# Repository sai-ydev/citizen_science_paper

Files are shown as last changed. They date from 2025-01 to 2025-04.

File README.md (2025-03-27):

# Purple Daisy RP2350A STEAM Platform #

This is the repository for the Purple Daisy Platform based on the [Raspberry Pi RP2350A Microcontroller](https://www.raspberrypi.com/products/rp2350/). This is an open-source platform to conduct citizen science experiments using the Raspberry Pi RP2350A microcontroller. 

The board looks something like shown in the image below:

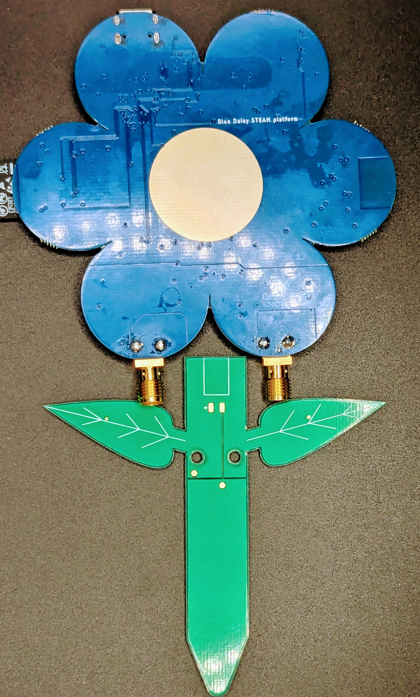
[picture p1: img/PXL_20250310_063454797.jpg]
Purple Daisy Front

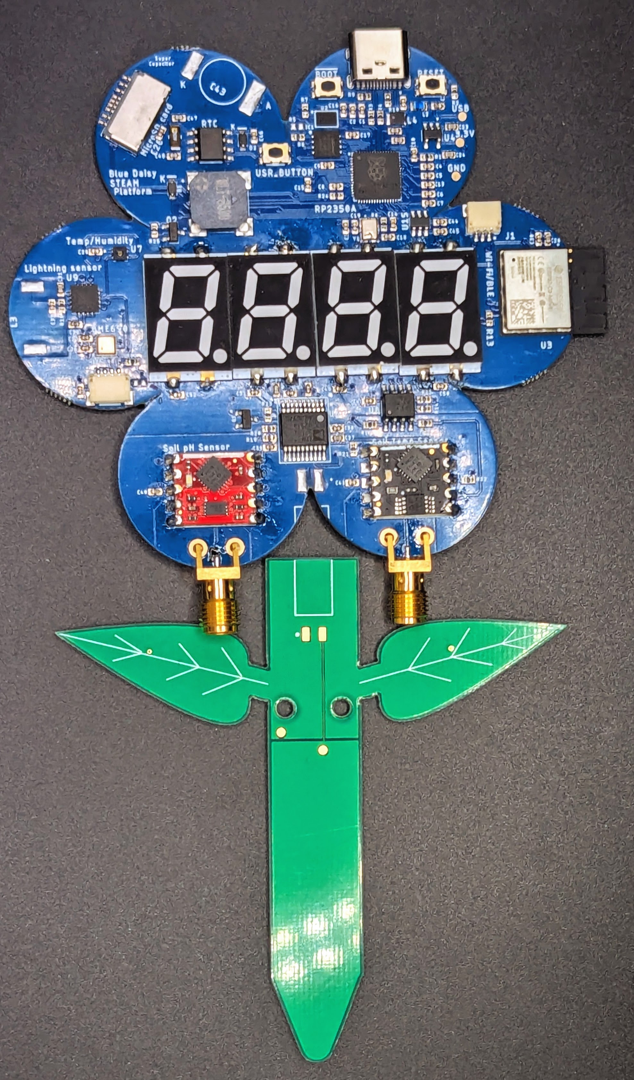
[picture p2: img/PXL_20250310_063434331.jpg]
Purple Daisy


The components of the board are highlighted in the image below. They are as follows:

1. Raspberry PI RP2350A microcontroller
2. RGB seven segment display - 4 characters
3. MicroSD card slot
4. Buzzer
5. WiFi Module
6. USB-C port
7. Soil Moisture sensor
8. AS3935 Lightning Sensor
9. pH Sensor + Conditioning Circuit
10. Liquid Temperature sensor
11. QwiiC I2C Sensor port to connect additional sensors
12. Real Time Clock for Calendar Keeping
13. Debug Port for debugging
14. BME690 Air Quality Sensor
15. ENS210 Temperature Humidity Sensor

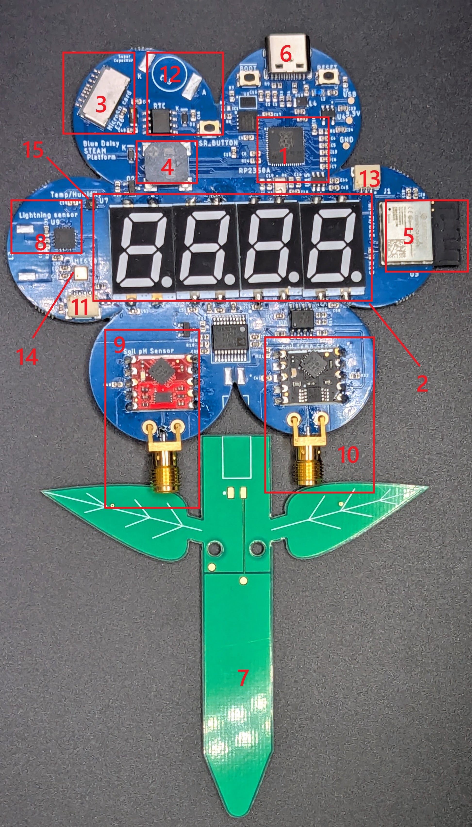
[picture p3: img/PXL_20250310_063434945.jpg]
Highlights


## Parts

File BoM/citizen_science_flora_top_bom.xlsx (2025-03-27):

Comment | Designator | Footprint | LCSC Part #
 | J3 | JST-4-1.25 | C160404
0.1uF | C1 C2 C3 C4 C5 C6 C7 C8 C9 C13 C15 C16 C17 C21 C22 C25 C26 C27 C28 C29 C30 C34 C36 C38 C39 C40 C41 C42 C44 C45 C46 C49 C50 C51 C52 | 0402-TIGHT | C1525
1.0uF | C32 | 0402 | C14445
1K | R2 R6 R8 R14 R15 | 0402 | C11702
1M | R23 R24 | 0402 | C26083
1N5819 | D1 D2 | SOD-323 | C2100
1nF | C33 | 0402 | C1523
2.2K | R12 R21 R22 | 0402 | C25879
3.3µH | L4 | 0805 | C42411119
4.7uF | C10 C11 C12 C14 | 0402-TIGHT | C23733
5.1k | R9 R10 | 0402 | C25905
10K | R18 R20 R7 R13 | 0402-TIGHT | C25531
10uF | C20 C23 C24 C31 C35 C37 | 0402-TIGHT | C15525
12MHz | Y1 | CRYSTAL-SMD-3.2X2.5MM | C20625731
12pF | C47 C48 | 0402 | C1547
15pF | C18 C19 | 0402 | C1548
16.9K | R19 | 0402 | C25858
DNP | R5 | 0402 | DNF
27 | R3 R4 | 0402-TIGHT | C3017771
33 | R1 | 0402 | C25105
100 | R16 R17 | 0402-TIGHT | C25076
BSS138 | Q1 Q2 | SOT23-3 | C12298
470 | R25 | 0402 | C208892
60312202114511 | J4 J5 | 60312202114511 | DNF
ADM3260ARSZ | U6 | SSOP20 | C658204
APS6404L-3SQR-ZR | U2 | APS6404L-3SQR-ZR | C3040877
AS3935-BQFT | U9 | QFN65P400X400X80-17N | C3178344
BME690 | U5 | IC_BME688 | BME690
DNF | R11 | 0402 | DNF
ENS210-LQFM | U7 | XDCR_ENS210-LQFM | C2991202
ESP32-C3-MINI-1-N4 | U3 | XCVR_ESP32-C3-MINI-1-N4 | C2934569
LQW18AN2N2D10D | L2 | INDC1608X100N | C71648
MA5532-AE | L3 | MA5532-AE | DNF
MIC5504-3.3YM5-T5 | U4 | SOT95P280X145-5N | C3021093
MLT-8530 | LS1 | XDCR_CMT-8504-100-SMT-TR | C94599
MOMENTARY-SWITCH-SPST-SMD-4.6X2.8MM | !BOOT RESET USR_BUTTON | TACTILE_SWITCH_SMD_4.6X2.8MM | C72443
OPS-S56AAF5 | U11 U12 U13 U14 | OPS-S56AAF5 | DNF
PCF8563T/F4 118 | U10 | SOIC127P600X175-8N | C80798
PH-OEM | U$2 U$3 | PH_SENSOR | DNF
Q13FC1350000400 | XTAL1 | XTAL_FC-135_EPS | C48615
RP2350A | U1 | RP2350A | C42411118
RSCSK2043R3D01004T | C43 | RSCSK2043R3D01004T | DNF
SFH6325-X017TEL0631 | U8 | SOIC127P599X175-8N | C465944
SM03B-SRSS-TB(LF)(SN) | J1 | JST_SM03B-SRSS-TB(LF)(SN) | C160403
SN74LVC1T45DBVRG4 | U15 | SOT95P280X145-6N | C7843
TF-123-ARP9HXX | U$1 | MICROSDCARD | C2982548
TPB1 27 | 3.3V | B1 27 | DNF
TPB1 27 | GND | B1 27 | DNF
TSM-102-02-S-SH | J6 | SAMTEC_TSM-102-02-S-SH | DNF
TYPE-C-31-M-12 | J2 | HRO_TYPE-C-31-M-12 | C165948
V_USB | USB | B1 27 | DNF
W25Q64JVXGIQ | IC1 | SON80P400X400X50-9N | C2940195

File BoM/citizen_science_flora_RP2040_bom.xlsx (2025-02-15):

Comment | Designator | Footprint | LCSC Part #
Qwiic | J3 | JST_SM04B-SRSS-TB(LF)(SN) | C160404
12MHz | Q3 | NXP-3225 | C20625731
0.1uF | C1 C2 C5 C6 C7 C8 C9 C10 C11 C14 C17 C21 C22 C25 C26 C27 C28 C29 C30 C34 C36 C38 C39 C40 C41 C42 C44 C45 C46 C49 C50 C51 C52 | 0402 | C1525
1.0uF | C3 C4 C32 | 0402 | C14445
1K | R2 R6 R7 R14 R15 | 0402 | C11702
1M | R23 R24 | 0402 | C26083
1N5819 | D1 D2 | SOD-323 | C2100
Blue LED | D3 | 0603 | C2287
1nF | C33 | 0402 | C1523
2.2K | R12 R21 R22 | 0402 | C25879
5.1k | R9 R10 | 0402 | C25905
10uF | C20 C23 C24 C31 C35 C37 | 0402 | C15525
10k | R13 R18 R20 | 0402 | C25531
12pF | C12 C13 C47 C48 | 0402 | C1547
16.9K | R19 | 0402 | C25858
27 | R1 R3 | 0402 | C3017771
100 | R4 R16 R17 | 0402 | C25076
470 | R25 | 0402 | C208892
60312202114511 | J4 J5 | 60312202114511 | DNF
ADM3260ARSZ | U6 | SSOP20 | C658204
AS3935-BQFT | U9 | QFN65P400X400X80-17N | C3178344
BME690 | U5 | IC_BME688 | BME690
BSS138 | Q1 Q2 | SOT95P240X111-3N | C12298
DNF | R5 R11 | 0402 | DNF
ENS210-LQFM | U7 | XDCR_ENS210-LQFM | C2991202
ESP32-C3-MINI-1-N4 | U3 | XCVR_ESP32-C3-MINI-1-N4 | C2934569
LQW18AN2N2D10D | L2 | INDC1608X100N | C71648
MA5532-AE | L3 | MA5532-AE | DNF
MIC5504-3.3YM5-T5 | U4 | SOT95P280X145-5N | C3021093
MLT-8530 | LS1 | XDCR_CMT-8504-100-SMT-TR | C94599
MOMENTARY-SWITCH-SPST-SMD-4.6X2.8MM | !BOOT RESET USER_BUTTON | TACTILE_SWITCH_SMD_4.6X2.8MM | C72443
OPS-S56AAF5 | U11 U12 U13 U14 | OPS-S56AAF5 | DNF
PCF8563T/F4 118 | U10 | SOIC127P600X175-8N | C80798
PH-OEM | U$2 U$3 | PH_SENSOR | DNF
Q13FC1350000400 | XTAL1 | XTAL_FC-135_EPS | C48615
RP2040 | U1 | QFN40P700X700X90-57N | C2040
RSCSK2043R3D01004T | C43 | RSCSK2043R3D01004T | DNF
SFH6325-X017TEL0631 | U8 | SOIC127P599X175-8N | C465944
SM03B-SRSS-TB(LF)(SN) | J1 | JST_SM03B-SRSS-TB(LF)(SN) | C160403
SN74LVC1T45DBVRG4 | U15 | SOT95P280X145-6N | C7843
TF-123-ARP9HXX | U$1 | MICROSDCARD | C2982548
TPB1 27 | 3.3V | B1 27 | DNF
TPB1 27 | GND | B1 27 | DNF
TSM-102-02-S-SH | J6 | SAMTEC_TSM-102-02-S-SH | DNF
TYPE-C-31-M-12 | J2 | HRO_TYPE-C-31-M-12 | C165948
V_USB | USB | B1 27 | DNF
W25Q64JVXGIQ | IC1 | SON80P400X400X50-9N | C2940195

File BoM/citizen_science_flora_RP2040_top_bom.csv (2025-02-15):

Comment | Designator | Footprint | LCSC Part #
0.1uF | D3 J3 Q3 C1 C2 C5 C6 C7 C8 C9 C10 C11 C14 C17 C21 C22 C25 C26 C27 C28 C29 C30 C34 C36 C38 C39 C40 C41 C42 C44 C45 C46 C49 C50 C51 C52 | 0402
1.0uF | C3 C4 C32 | 0402
1K | R2 R6 R14 R15 | 0402
1KOHM-0402-1/16W-1% | R7 | 0402
1M | R23 R24 | 0402
1N4148 | D1 | SOD-323
1N5819 | D2 | SOD-323
1nF | C33 | 0402
2.2K | R12 R21 R22 | 0402
5.1k | R9 R10 | 0402
10UF0402 | C20 C23 C24 C31 C35 C37 | 0402
10k | R13 R18 R20 | 0402
12pF | C12 C13 C47 C48 | 0402
16.9K | R19 | 0402
27OHM0402 | R1 R3 | 0402
100OHM | R4 R16 R17 | 0402
470 | R25 | 0402
60312202114511 | J4 J5 | 60312202114511
ADM3260ARSZ | U6 | SSOP20
AS3935-BQFT | U9 | QFN65P400X400X80-17N
BME690 | U5 | IC_BME688
BSS138 | Q1 Q2 | SOT95P240X111-3N
DNF | R5 R11 | 0402
ENS210-LQFM | U7 | XDCR_ENS210-LQFM
ESP32-C3-MINI-1-N4 | U3 | XCVR_ESP32-C3-MINI-1-N4
LQW18AN2N2D10D | L2 | INDC1608X100N
MA5532-AE | L3 | MA5532-AE
MIC5504-3.3YM5-T5 | U4 | SOT95P280X145-5N
MLT-8530 | LS1 | XDCR_CMT-8504-100-SMT-TR
MOMENTARY-SWITCH-SPST-SMD-4.6X2.8MM | !BOOT RESET USER_BUTTON | TACTILE_SWITCH_SMD_4.6X2.8MM
OPS-S56AAF5 | U11 U12 U13 U14 | OPS-S56AAF5
PCF8563T/F4 118 | U10 | SOIC127P600X175-8N
PH-OEM | U$2 U$3 | PH_SENSOR
Q13FC1350000400 | XTAL1 | XTAL_FC-135_EPS
RP2040 | U1 | QFN40P700X700X90-57N
RSCSK2043R3D01004T | C43 | RSCSK2043R3D01004T
SFH6325-X017TEL0631 | U8 | SOIC127P599X175-8N
SM03B-SRSS-TB(LF)(SN) | J1 | JST_SM03B-SRSS-TB(LF)(SN)
SN74LVC1T45DBVRG4 | U15 | SOT95P280X145-6N
TF-123-ARP9HXX | U$1 | MICROSDCARD
TPB1 27 | 3.3V | B1 27
TPB1 27 | GND | B1 27
TSM-102-02-S-SH | J6 | SAMTEC_TSM-102-02-S-SH
TYPE-C-31-M-12 | J2 | HRO_TYPE-C-31-M-12
V_USB | USB | B1 27
W25Q64JVXGIQ | IC1 | SON80P400X400X50-9N

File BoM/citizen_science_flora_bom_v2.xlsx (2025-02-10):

Comment | Designator | *Manufacturer Part Number | *Quantity | Manufacturer(Optional) | Package(Optional)
SM04B-SRSS-TB(LF)(SN) | J3 | SM04B-SRSS-TB(LF)(SN) | 1 | JST | SMD,P=1mm,Surface Mount，Right Angle
0.1uF | C1,C2,C3,C4,C5,C6,C7,C8,C9,C13,C15,C16,C17,C21,C22,C25,C26,C27,C28,C29,C30,C34,C36,C38,C39,C40,C41,C42,C44,C45,C46,C49,C50,C51,C52 | 0402B104K250NT | 35 | FH | 0402
1.0uF | C32 | CL05A105KP5NNNC | 1 | Samsung | 0402
1K | R2,R6,R8,R14,R15 | 0402WGF1001TCE | 5 | Uni-Royal | 0402
1M | R23,R24 | 0402WGF1004TCE | 2 | Uni-Royal | 0402
1N5819 | D1,D2 | 1SS404 | 2 | Jiangsu Changjing | SOD-323
1nF | C33 | 0402B102K500NT | 1 | FH | 0402
2.2K | R12,R21,R22 | 0402WGF2201TCE | 3 | Uni-Royal | 0402
3.3µH | L1 | AOTA-B201610S3R3-101-T | 1 | Abracon | 0806
4.7uF | C10,C11,C12,C14 | CL05A475MP5NRNC | 4 | Samsung | 0402
5.1k | R9,R10 | 0402WGF5101TCE | 2 | Uni-Royal | 0402
10K | R18,R20,R7,R13 | 0402WGJ0103TCE | 4 | Uni-Royal | 0402
10uF | C20,C23,C24,C31,C35,C37 | CL05A106MQ5NUNC | 6 | Samsung | 0402
12MHz | Y1 | ABM8-272-T3 | 1 | Abracon | SMD3225-4P
12pF | C47,C48 | 0402CG120J500NT | 2 | FH | 0402
15pF | C18,C19 | 0402CG150J500NT | 2 | FH | 0402
16.9K | R19 | 0402WGF1692TCE | 1 | Uni-Royal | 0402
27 | R3,R4 | SCR0603J27R | 2 | VO | 0402
33 | R1 | 0402WGF330JTCE | 1 | Uni-Royal | 0402
100 | R16,R17 | 0402WGF1000TCE | 2 | Uni-Royal | 0402
BSS138 | Q1,Q2 | Si2308BDS-T1-GE3 | 2 | Vishay | SOT-23-3
470 | R25 | RMS04FT4700 | 1 | TA-I Tech | 0402
ADM3260ARSZ | U6 | ADM3260ARSZ | 1 | Analog Devices | SSOP-20
APS6404L-3SQR-ZR | U2 | APS6404L-3SQR-ZR | 1 | Ap Memory | USON8
AS3935-BQFT | U9 | AS3935-BQFT | 1 | Sciosense | 16LD MLPQ
BME690 | U5 | BME690 | 1 | Bosch | LGA-8_3x3mm
ENS210-LQFM | U7 | ENS210-LQFM | 1 | Sciosense | QFN4_2x2mm
ESP32-C3-MINI-1-N4 | U3 | ESP32-C3-MINI-1-N4 | 1 | Espressif | ESP32-C3-MINI-1-N4
LQW18AN2N2D10D | L2 | LQW18AN2N2C80D | 1 | Murata | 0603
MA5532-AE | L3 | MA5532-AE | 1 | Coil craft | SMD
MIC5504-3.3YM5-T5 | U4 | TPMIC5504-3.3YM5 | 1 | Tech Public | SOT-23-5
MLT-8530 | LS1 | MLT-8530 | 1 | Jiangsu Huaneng Elec | SMD
MOMENTARY-SWITCH-SPST-SMD-4.6X2.8MM | !BOOT,RESET,USR_BUTTON | KMR221GLFS | 3 | C&K | SMD
PCF8563T/F4 118 | U10 | PCF8563T/F4 118 | 1 | NXP | SOIC-8
Q13FC1350000400 | XTAL1 | Q13FC13500002 | 1 | Seiko Epson | SMD3215-2P
RP2350A | U1 | RP2350A | 1 | Raspberry Pi | QFN-60
RSCSK2043R3D01004T | C43 | RSCSK2043R3D01004T | 1 | Elna America | SMD
SFH6325-X017TEL0631 | U8 | EL0631(TA) | 1 | Everlight Electronics | SOP-8
SM03B-SRSS-TB(LF)(SN) | J1 | SM03B-SRSS-TB(LF)(SN) | 1 | JST | SMD,P=1mm,Surface Mount，Right Angle
SN74LVC1T45DBVRG4 | U15 | SN74LVC1T45DBVRG4 | 1 | Texas Instruments | SOT-23-6
TF-123-ARP9HXX | U$1 | TF-123-ARP9H17 | 1 | Xunpu | SMD
TYPE-C-31-M-12 | J2 | TYPE-C-31-M-12 | 1 | Korean Hroparts | SMD
W25Q64JVXGIQ | IC1 | W25Q64JVXGIQ | 1 | Winbond | XSON-8-EP(4x4)

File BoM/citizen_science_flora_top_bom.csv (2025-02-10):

Comment | Designator | Footprint | LCSC Part #
 | J3 R5 | 0402
0.1uF | C1 C2 C3 C4 C5 C6 C7 C8 C9 C13 C15 C16 C17 | 0402-TIGHT
0.1uF | C21 C22 | 0402
0.1uF | C25 C26 C27 C28 C29 | 0402-TIGHT
0.1uF | C30 | 0402
0.1uF | C34 C36 C38 C39 C40 C41 C42 | 0402-TIGHT
0.1uF | C44 C45 C46 C49 C50 C51 C52 | 0402
1.0uF | C32 | 0402
1K | R2 R6 R8 R14 R15 | 0402
1M | R23 R24 | 0402
1N4148 | D1 | SOD-323
1N5819 | D2 | SOD-323
1nF | C33 | 0402
2.2K | R12 R21 R22 | 0402
3.3uH | L4 | IND_LQH2MCN120K02L
4.7uF | C10 C11 C12 C14 | 0402-TIGHT
5.1k | R9 R10 | 0402
10K | R18 R20 | 0402-TIGHT
10k | R7 R13 | 0402
10uF | C20 C23 C24 C31 C35 C37 | 0402-TIGHT
12MHz | Y1 | CRYSTAL-SMD-3.2X2.5MM
12pF | C47 C48 | 0402
15pF | C18 C19 | 0402
16.9K | R19 | 0402
27 | R3 R4 | 0402-TIGHT
33 | R1 | 0402
100 | R16 R17 | 0402-TIGHT
220mA/50V/3.5Ω | Q1 | SOT23-3
470 | R25 | 0402
60312202114511 | J4 J5 | 60312202114511
ADM3260ARSZ | U6 | SSOP20
APS6404L-3SQR-ZR | U2 | APS6404L-3SQR-ZR
AS3935-BQFT | U9 | QFN65P400X400X80-17N
BME690 | U5 | IC_BME688
BSS138 | Q2 | SOT323
DNF | R11 | 0402
ENS210-LQFM | U7 | XDCR_ENS210-LQFM
ESP32-C3-MINI-1-N4 | U3 | XCVR_ESP32-C3-MINI-1-N4
LQW18AN2N2D10D | L2 | INDC1608X100N
MA5532-AE | L3 | MA5532-AE
MIC5504-3.3YM5-T5 | U4 | SOT95P280X145-5N
MLT-8530 | LS1 | XDCR_CMT-8504-100-SMT-TR
MOMENTARY-SWITCH-SPST-SMD-4.6X2.8MM | !BOOT RESET USR_BUTTON | TACTILE_SWITCH_SMD_4.6X2.8MM
OPS-S56AAF5 | U11 U12 U13 U14 | OPS-S56AAF5
PCF8563T/F4 118 | U10 | SOIC127P600X175-8N
PH-OEM | U$2 U$3 | PH_SENSOR
Q13FC1350000400 | XTAL1 | XTAL_FC-135_EPS
RP2350A | U1 | RP2350A
RSCSK2043R3D01004T | C43 | RSCSK2043R3D01004T
SFH6325-X017TEL0631 | U8 | SOIC127P599X175-8N
SM03B-SRSS-TB(LF)(SN) | J1 | JST_SM03B-SRSS-TB(LF)(SN)
SN74LVC1T45DBVRG4 | U15 | SOT95P280X145-6N
TF-123-ARP9HXX | U$1 | MICROSDCARD
TPB1 27 | 3.3V | B1 27
TPB1 27 | GND | B1 27
TSM-102-02-S-SH | J6 | SAMTEC_TSM-102-02-S-SH
TYPE-C-31-M-12 | J2 | HRO_TYPE-C-31-M-12
V_USB | USB | B1 27
W25Q64JVXGIQ | IC1 | SON80P400X400X50-9N

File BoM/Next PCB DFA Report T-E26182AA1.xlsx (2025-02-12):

NEXTPCB DFA report
Project Number： |  | Prepared by: |  |  |  |  | Date: 20250210
Item | Problem description 问题描述 | Reference location 影响位置 | MPN 物料名称 | Impact 影响 | Image 图片 | NextPCB Suggestion 建议 | Customer feedback 客户反馈 | Severity 严重度 | Status 状态
1 | Is the length and width of the slot of J2 measured by taking the center of the outline frame of the outline layer as the base point？ | J2 |  | We are not sure. |  | please confirm. | They are taken by using the PCB edge as a reference. Attaching an image. | High | open
2 | The width of the pads is too short in gerber. | R3,R4 |  | The component can not be 100% soldered on the board which will cause soldering issue. |  | please modify the width of the pads to 0.8mm according to the datasheet. | Fixed | High | open
3 | The pads are too close.The pitch of the pads should be 1.9mm while it is only 1.3mm in gerber. | Q2 |  | The component can not be 100% soldered on the board which will cause soldering issue. |  | please modify the footprint according to the datasheet.You can refer to the layout recommended in the datasheet. | Fixed | High | open
4 | Where is PIN1？ | Y1,U10 |  | —— |  | please point out in the silk layer or point out in the picture. | Fixed | Middle | open
5 | Is that the cathode where the arrow is pointing? | C43,D1,D2 |  | We are not sure about the polarity. |  | please confirm. | Fixed | Middle | open

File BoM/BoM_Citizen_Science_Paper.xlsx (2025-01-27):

Description | Quantity | Price | Link
pH Sensor | 1 | 84.99 | https://atlas-scientific.com/probes/ph-probe/
pH circuit | 1 | 45.99 | https://atlas-scientific.com/embedded-solutions/ph-oem-circuit/
Temperature Probe | 1 | 23.99 | https://atlas-scientific.com/probes/spike-tip-temp-probe/
Temperature Reading Module | 1 | 35.99 | https://atlas-scientific.com/product/rtd-2-temperature-oem-circuit/
BME690 Air Quality Sensor | 1 | 12.59 | https://www.mouser.com/ProductDetail/Bosch-Sensortec/BME690
AS3935 Lightning Sensor | 1 | 6.66 | https://www.mouser.com/ProductDetail/ScioSense/AS3935-BQFT
ENS210 Atmospheric Temperature Sensor | 1 | 1.57 | https://www.mouser.com/ProductDetail/ScioSense/ENS210-LQFM
Seven Segment Display | 4 | 2.5 | https://opledtw.com
PCB | 1 | 5 | https://jlcpcb.com
PCB assembly | 1 | 20 | https://jlcpcb.com

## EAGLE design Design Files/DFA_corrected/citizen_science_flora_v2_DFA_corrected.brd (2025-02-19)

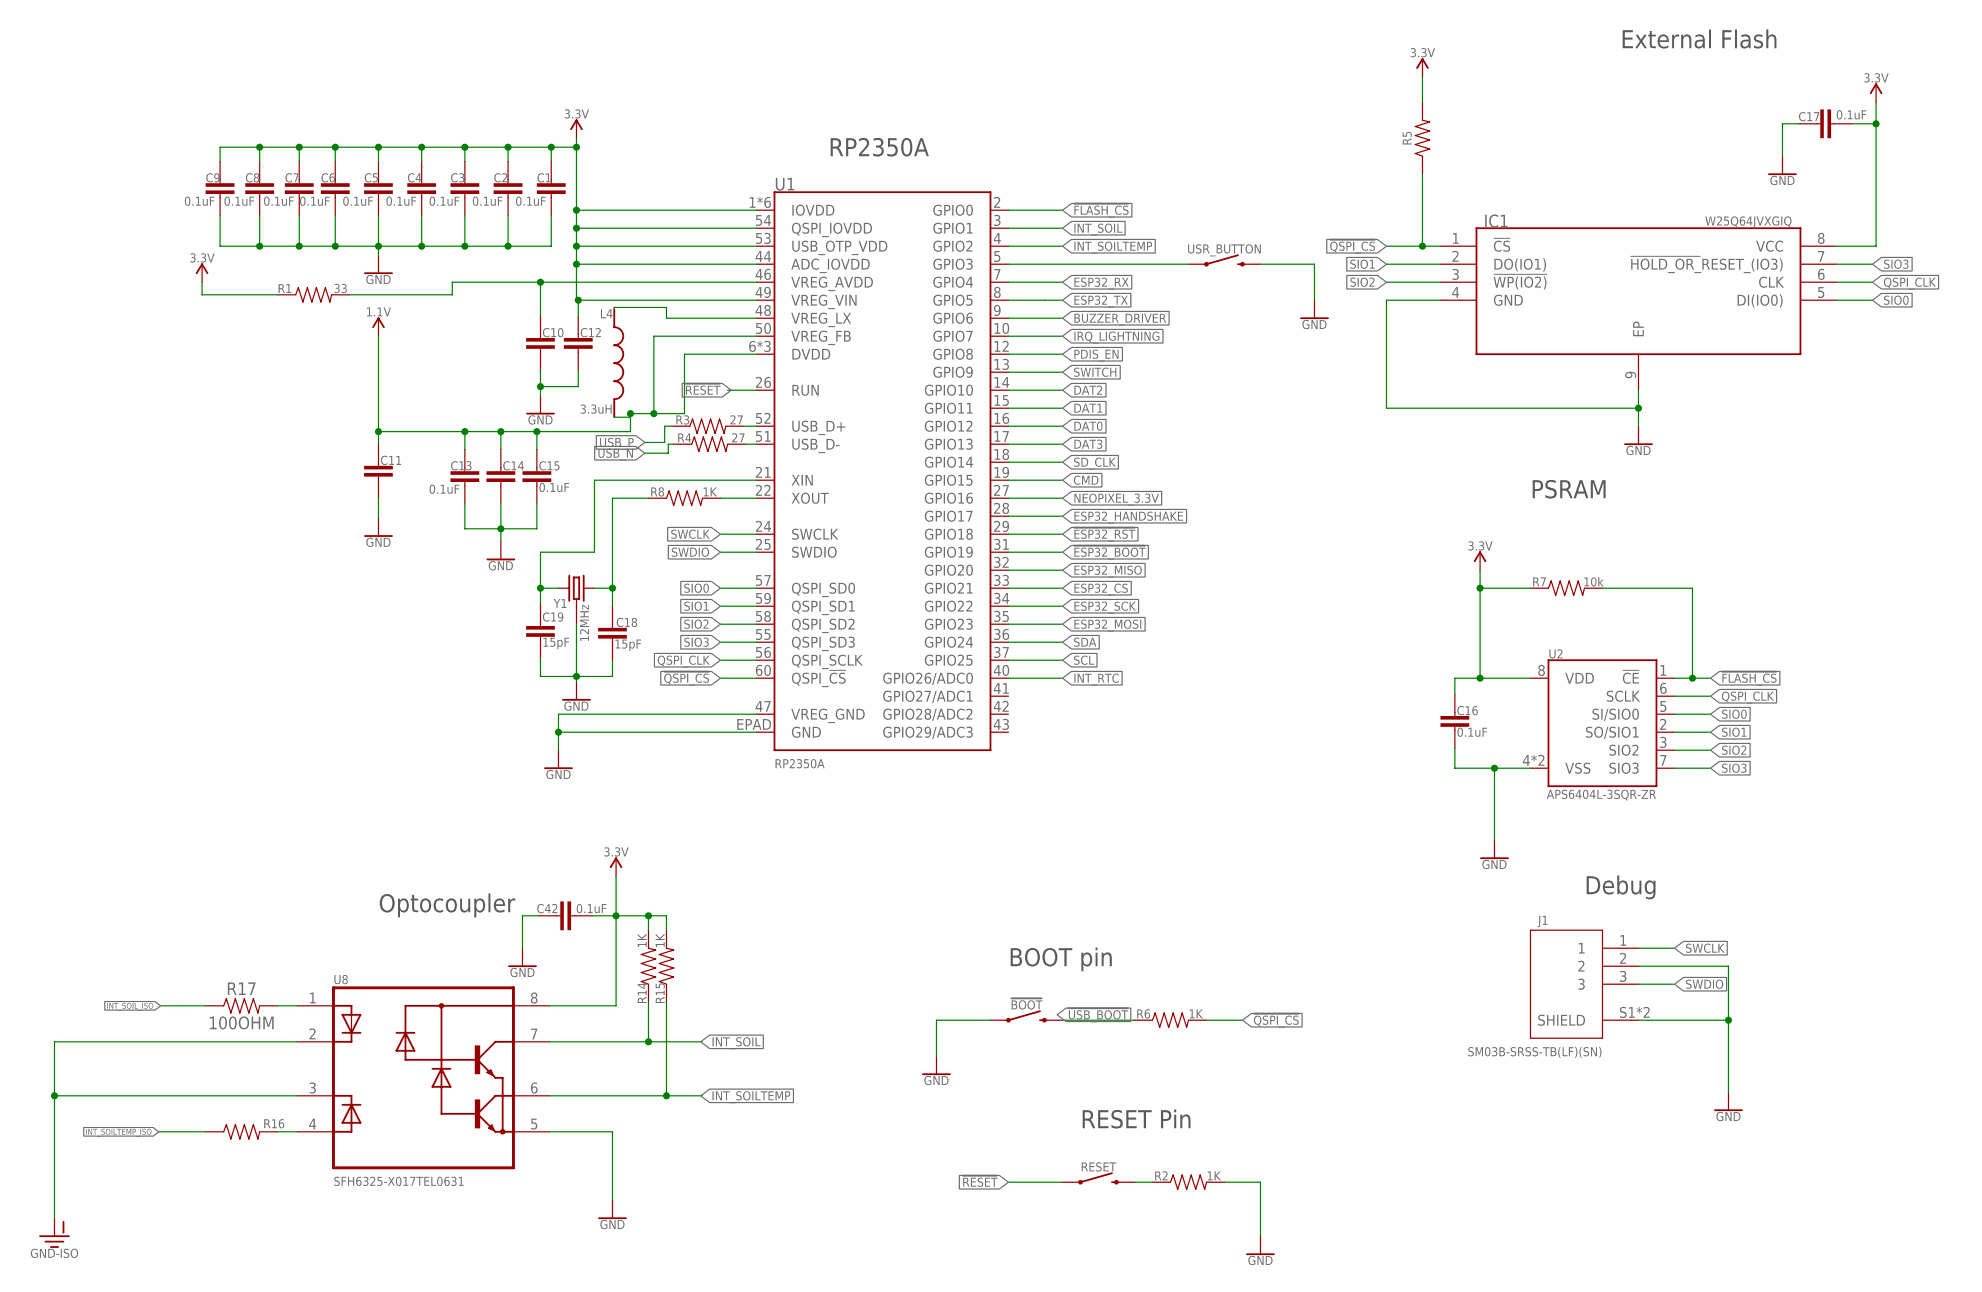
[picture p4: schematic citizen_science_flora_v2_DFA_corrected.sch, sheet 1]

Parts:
!BOOT: MOMENTARY-SWITCH-SPST-SMD-4.6X2.8MM; TACTILE_SWITCH_SMD_4.6X2.8MM
C1, C2, C3, C4, C5, C6, C7, C8, C9, C13, C15, C16, C17, C42: 0.1uF; 0402
C10, C11, C12, C14: 4.7UF0402; 0402
C18, C19: 15pF; 0402
IC1: W25Q64JVXGIQ; SON80P400X400X50-9N
J1: SM03B-SRSS-TB(LF)(SN); JST_SM03B-SRSS-TB(LF)(SN)
L4: 3.3uH; IND_LQH2MCN120K02L
R1: 33; 0402
R2, R6, R8, R14, R15: 1K; 0402
R3, R4: 27; 0402
R5: 0402
R7: 10k; 0402
R16, R17: 100OHM; 0402
RESET: MOMENTARY-SWITCH-SPST-SMD-4.6X2.8MM; TACTILE_SWITCH_SMD_4.6X2.8MM
U1: RP2350A
U2: APS6404L-3SQR-ZR
U8: SFH6325-X017TEL0631; SOIC127P599X175-8N
USR_BUTTON: MOMENTARY-SWITCH-SPST-SMD-4.6X2.8MM; TACTILE_SWITCH_SMD_4.6X2.8MM
Y1: 12MHz; CRYSTAL-SMD-3.2X2.5MM

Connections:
1.1V: C11.1, C13.1, C14.1, C15.1, L4.2, U1.6 (DVDD), U1.23 (DVDD), U1.39 (DVDD), U1.50 (VREG_FB)
3.3V: C1.1, C2.1, C3.1, C4.1, C5.1, C6.1, C7.1, C8.1, C9.1, C12.1, C16.1, C17.2, C42.2, IC1.8 (VCC), R1.1, R5.2, R7.1, R14.2, R15.2, U1.1 (IOVDD), U1.11 (IOVDD), U1.20 (IOVDD), U1.30 (IOVDD), U1.38 (IOVDD), U1.44 (ADC_IOVDD), U1.45 (IOVDD), U1.49 (VREG_VIN), U1.53 (USB_OTP_VDD), U1.54 (QSPI_IOVDD), U2.8 (VDD), U8.8 (C(VCC)); also elsewhere on the board
!ESP32_BOOT: U1.31 (GPIO19); also elsewhere on the board
!ESP32_RST: U1.29 (GPIO18); also elsewhere on the board
!FLASH_CS: R7.2, U1.2 (GPIO0), U2.1 (!CE!)
!QSPI_CS: IC1.1 (!CS), R5.1, R6.2, U1.60 (QSPI_!CS!)
!RESET: RESET.1, RESET.2 (1), U1.26 (RUN)
!USB_BOOT: !BOOT.3 (2), !BOOT.4 (2), R6.1
BUZZER_DRIVER: U1.9 (GPIO6); also elsewhere on the board
CMD: U1.19 (GPIO15); also elsewhere on the board
DAT0: U1.16 (GPIO12); also elsewhere on the board
DAT1: U1.15 (GPIO11); also elsewhere on the board
DAT2: U1.14 (GPIO10); also elsewhere on the board
DAT3: U1.17 (GPIO13); also elsewhere on the board
ESP32_CS: U1.33 (GPIO21); also elsewhere on the board
ESP32_HANDSHAKE: U1.28 (GPIO17); also elsewhere on the board
ESP32_MISO: U1.32 (GPIO20); also elsewhere on the board
ESP32_MOSI: U1.35 (GPIO23); also elsewhere on the board
ESP32_RX: U1.7 (GPIO4); also elsewhere on the board
ESP32_SCK: U1.34 (GPIO22); also elsewhere on the board
ESP32_TX: U1.8 (GPIO5); also elsewhere on the board
GND: !BOOT.1, !BOOT.2 (1), C1.2, C2.2, C3.2, C4.2, C5.2, C6.2, C7.2, C8.2, C9.2, C10.2, C11.2, C12.2, C13.2, C14.2, C15.2, C16.2, C17.1, C18.2, C19.2, C42.1, IC1.4 (GND), IC1.9 (EP), J1.2, J1.S1 (SHIELD), J1.S2 (SHIELD), R2.2, U1.47 (VREG_GND), U1.EPAD (GND), U2.4 (VSS), U2.9 (VSS), U8.5 (E(GND)), USR_BUTTON.3 (2), USR_BUTTON.4 (2), Y1.2 (GND), Y1.4 (GND); also elsewhere on the board
GND-ISO: U8.2 (C1), U8.3 (C2); also elsewhere on the board
INT_RTC: U1.40 (GPIO26/ADC0); also elsewhere on the board
INT_SOIL: R14.1, U1.3 (GPIO1), U8.7 (C1(VO1))
INT_SOILTEMP: R15.1, U1.4 (GPIO2), U8.6 (C2(VO2))
INT_SOILTEMP_ISO: R16.1; also elsewhere on the board
INT_SOIL_ISO: R17.1; also elsewhere on the board
IRQ_LIGHTNING: U1.10 (GPIO7); also elsewhere on the board
unnamed: C10.1, R1.2, U1.46 (VREG_AVDD)
unnamed: L4.1, U1.48 (VREG_LX)
unnamed: R2.1, RESET.3 (2), RESET.4 (2)
unnamed: C18.1, R8.1, Y1.3 (2)
unnamed: C19.1, U1.21 (XIN), Y1.1
unnamed: R8.2, U1.22 (XOUT)
unnamed: R16.2, U8.4 (A2)
unnamed: R17.2, U8.1 (A1)
unnamed: U1.5 (GPIO3), USR_BUTTON.1, USR_BUTTON.2 (1)
NEOPIXEL_3.3V: U1.27 (GPIO16); also elsewhere on the board
PDIS_EN: U1.12 (GPIO8); also elsewhere on the board
QSPI_CLK: IC1.6 (CLK), U1.56 (QSPI_SCLK), U2.6 (SCLK)
SCL: U1.37 (GPIO25); also elsewhere on the board
SDA: U1.36 (GPIO24); also elsewhere on the board
SD_CLK: U1.18 (GPIO14); also elsewhere on the board
SIO0: IC1.5 (DI(IO0)), U1.57 (QSPI_SD0), U2.5 (SI/SIO0)
SIO1: IC1.2 (DO(IO1)), U1.59 (QSPI_SD1), U2.2 (SO/SIO1)
SIO2: IC1.3 (!WP(IO2)), U1.58 (QSPI_SD2), U2.3 (SIO2)
SIO3: IC1.7 (!HOLD_OR_!RESET_(IO3)), U1.55 (QSPI_SD3), U2.7 (SIO3)
SWCLK: J1.1, U1.24 (SWCLK)
SWDIO: J1.3, U1.25 (SWDIO)
SWITCH: U1.13 (GPIO9); also elsewhere on the board
USBD_N: R4.2, U1.51 (USB_D-)
USBD_P: R3.2, U1.52 (USB_D+)
USB_N: R4.1; also elsewhere on the board
USB_P: R3.1; also elsewhere on the board

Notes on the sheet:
RP2350A
RESET Pin
External Flash
BOOT pin
PSRAM
Debug
Optocoupler

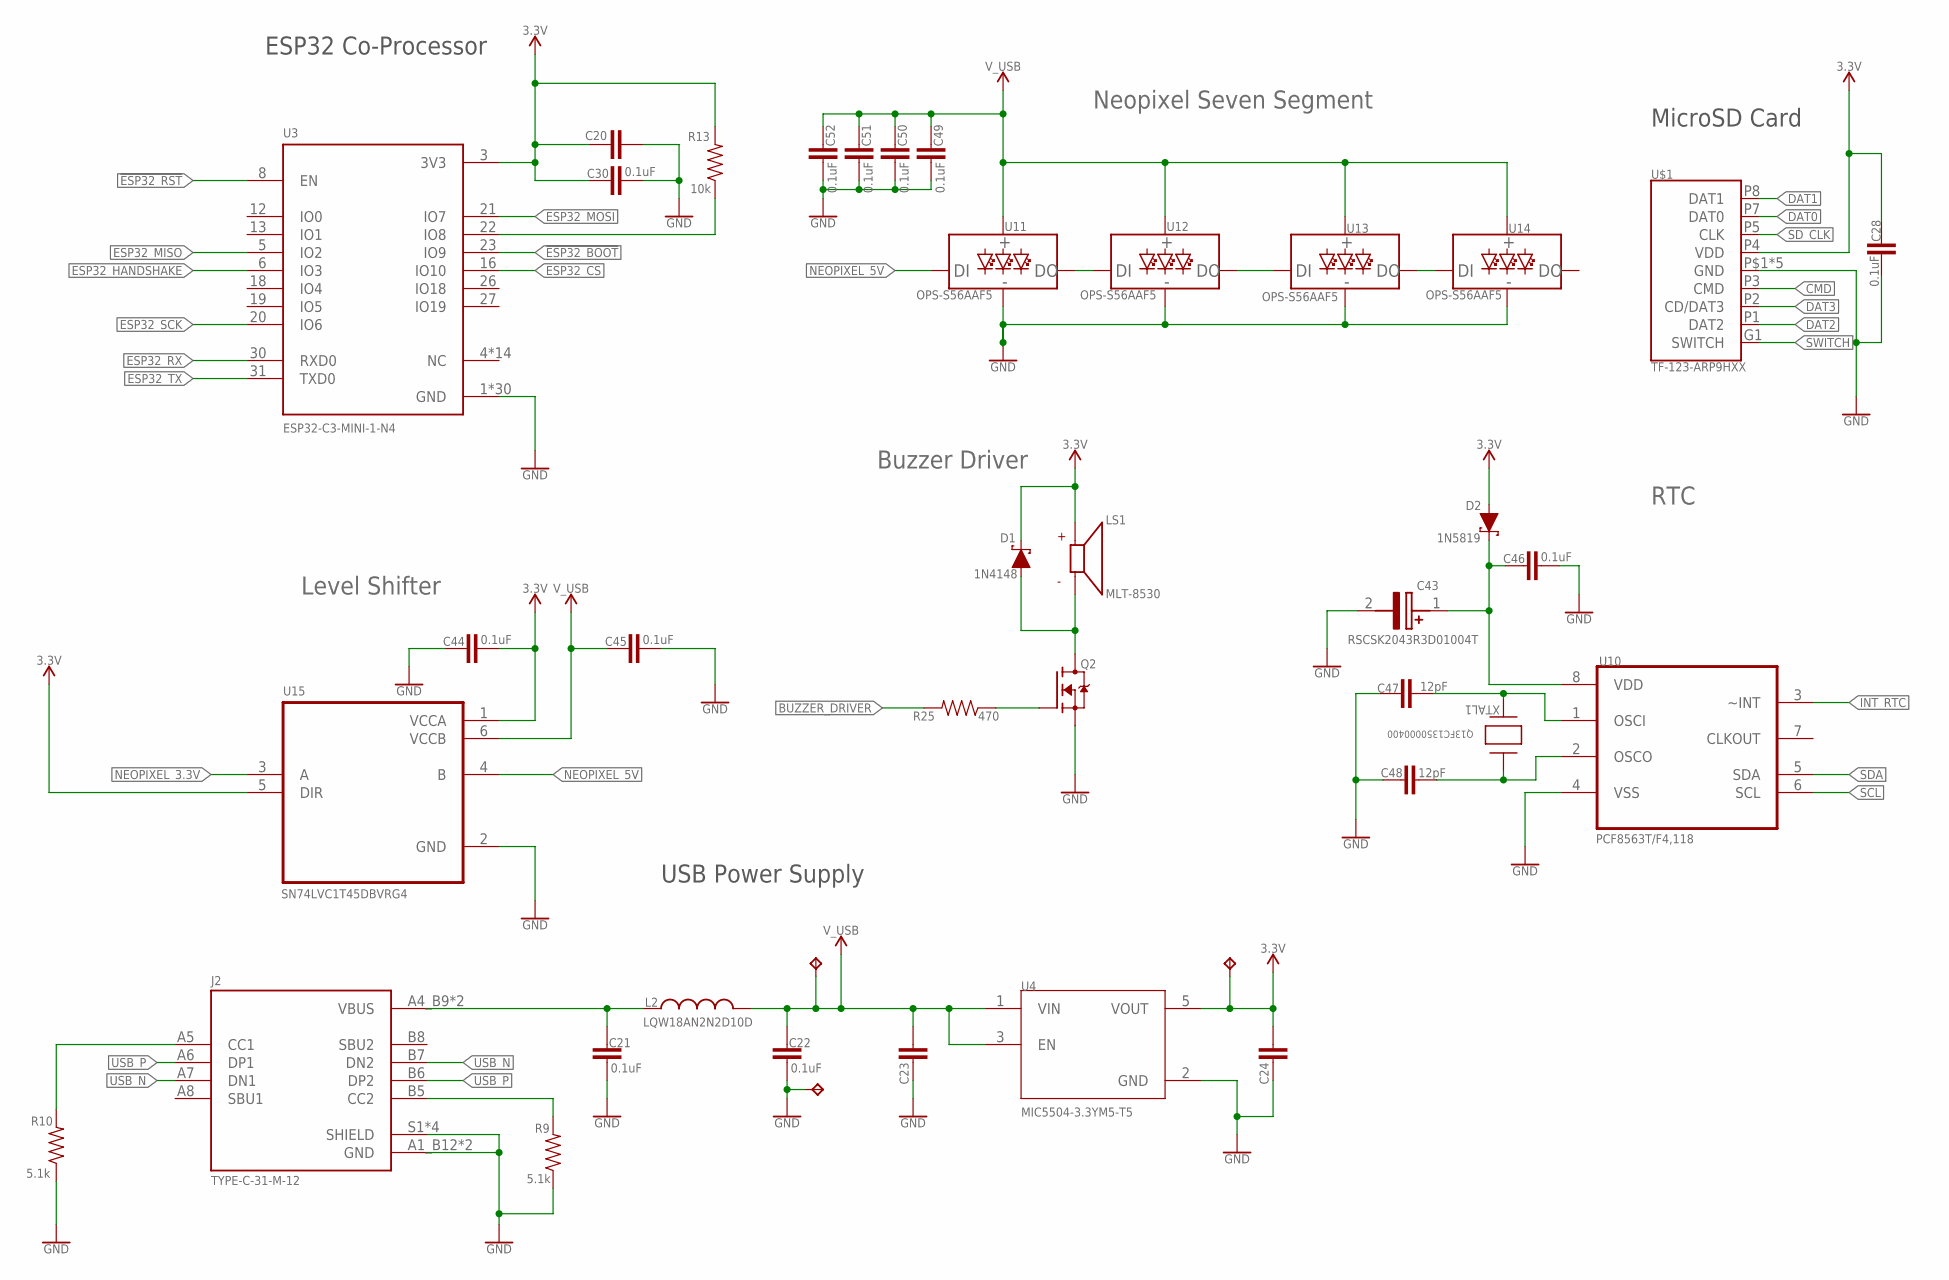
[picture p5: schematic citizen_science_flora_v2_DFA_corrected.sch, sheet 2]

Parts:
3.3V: TPB1,27; B1,27
C20, C23, C24: 10UF0402; 0402
C21, C22, C28, C30, C44, C45, C46, C49, C50, C51, C52: 0.1uF; 0402
C43: RSCSK2043R3D01004T
C47, C48: 12pF; 0402
D1: 1N4148; SOD-323
D2: 1N5819; SOD-323
GND: TPB1,27; B1,27
J2: TYPE-C-31-M-12; HRO_TYPE-C-31-M-12
L2: LQW18AN2N2D10D; INDC1608X100N
LS1: MLT-8530; XDCR_CMT-8504-100-SMT-TR
Q2: BSS138; SOT95P240X111-3N
R9, R10: 5.1k; 0402
R13: 10k; 0402
R25: 470; 0402
U3: ESP32-C3-MINI-1-N4; XCVR_ESP32-C3-MINI-1-N4
U4: MIC5504-3.3YM5-T5; SOT95P280X145-5N
U10: PCF8563T/F4,118; SOIC127P600X175-8N
U11, U12, U13, U14: OPS-S56AAF5
U15: SN74LVC1T45DBVRG4; SOT95P280X145-6N
U$1: TF-123-ARP9HXX; MICROSDCARD
USB: V_USB; B1,27
XTAL1: Q13FC1350000400; XTAL_FC-135_EPS

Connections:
3.3V: 3.3V.TP, C20.1, C24.2, C28.1, C30.1, C44.2, D1.C, D2.A, LS1.P, R13.2, U3.3 (3V3), U4.5 (VOUT), U15.1 (VCCA), U15.5 (DIR), U$1.P4 (VDD); also elsewhere on the board
!ESP32_BOOT: U3.23 (IO9); also elsewhere on the board
!ESP32_RST: U3.8 (EN); also elsewhere on the board
BUZZER_DRIVER: R25.2; also elsewhere on the board
CMD: U$1.P3 (CMD); also elsewhere on the board
DAT0: U$1.P7 (DAT0); also elsewhere on the board
DAT1: U$1.P8 (DAT1); also elsewhere on the board
DAT2: U$1.P1 (DAT2); also elsewhere on the board
DAT3: U$1.P2 (CD/DAT3); also elsewhere on the board
ESP32_CS: U3.16 (IO10); also elsewhere on the board
ESP32_HANDSHAKE: U3.6 (IO3); also elsewhere on the board
ESP32_MISO: U3.5 (IO2); also elsewhere on the board
ESP32_MOSI: U3.21 (IO7); also elsewhere on the board
ESP32_RX: U3.30 (RXD0); also elsewhere on the board
ESP32_SCK: U3.20 (IO6); also elsewhere on the board
ESP32_TX: U3.31 (TXD0); also elsewhere on the board
GND: C20.2, C21.2, C22.2, C23.1, C24.1, C28.2, C30.2, C43.2 (-), C44.1, C45.2, C46.2, C47.1, C48.1, C49.2, C50.2, C51.2, C52.2, GND.TP, J2.A1_B12 (GND), J2.B1_A12 (GND), J2.S1 (SHIELD), J2.S2 (SHIELD), J2.S3 (SHIELD), J2.S4 (SHIELD), Q2.2 (S), R9.1, R10.1, U3.1 (GND), U3.2 (GND), U3.11 (GND), U3.14 (GND), U3.36 (GND), U3.37 (GND), U3.38 (GND), U3.39 (GND), U3.40 (GND), U3.41 (GND), U3.42 (GND), U3.43 (GND), U3.44 (GND), U3.45 (GND), U3.46 (GND), U3.47 (GND), U3.48 (GND), U3.49_1 (GND), U3.49_2 (GND), U3.49_3 (GND), U3.49_4 (GND), U3.49_5 (GND), U3.49_6 (GND), U3.49_7 (GND), U3.49_8 (GND), U3.49_9 (GND), U3.50 (GND), U3.51 (GND), U3.52 (GND), U3.53 (GND), U4.2 (GND), U10.4 (VSS), U11.P$3 (GND), U12.P$3 (GND), U13.P$3 (GND), U14.P$3 (GND), U15.2 (GND), U$1.P6 (GND), U$1.P$1 (GND), U$1.P$2 (GND), U$1.P$3 (GND), U$1.P$4 (GND); also elsewhere on the board
INT_RTC: U10.3 (~INT); also elsewhere on the board
unnamed: J2.A5 (CC1), R10.2
unnamed: J2.B5 (CC2), R9.2
unnamed: C21.1, J2.A4_B9 (VBUS), J2.B4_A9 (VBUS), L2.1
unnamed: R13.1, U3.22 (IO8)
unnamed: U11.P$2 (DO), U12.P$4 (DI)
unnamed: U12.P$2 (DO), U13.P$4 (DI)
unnamed: U13.P$2 (DO), U14.P$4 (DI)
unnamed: D1.A, LS1.N, Q2.3 (D)
unnamed: Q2.1 (G), R25.1
unnamed: C43.1 (+), C46.1, D2.C, U10.8 (VDD)
unnamed: C48.2, U10.2 (OSCO), XTAL1.1
unnamed: C47.2, U10.1 (OSCI), XTAL1.2
NEOPIXEL_3.3V: U15.3 (A); also elsewhere on the board
NEOPIXEL_5V: U11.P$4 (DI), U15.4 (B)
SCL: U10.6 (SCL); also elsewhere on the board
SDA: U10.5 (SDA); also elsewhere on the board
SD_CLK: U$1.P5 (CLK); also elsewhere on the board
SWITCH: U$1.G1 (SWITCH); also elsewhere on the board
USB_N: J2.A7 (DN1), J2.B7 (DN2); also elsewhere on the board
USB_P: J2.A6 (DP1), J2.B6 (DP2); also elsewhere on the board
V_USB: C22.1, C23.2, C45.1, C49.1, C50.1, C51.1, C52.1, L2.2, U4.1 (VIN), U4.3 (EN), U11.P$1 (VCC), U12.P$1 (VCC), U13.P$1 (VCC), U14.P$1 (VCC), U15.6 (VCCB), USB.TP; also elsewhere on the board

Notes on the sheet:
MicroSD Card
ESP32 Co-Processor
USB Power Supply
Neopixel Seven Segment
Level Shifter
Buzzer Driver
RTC

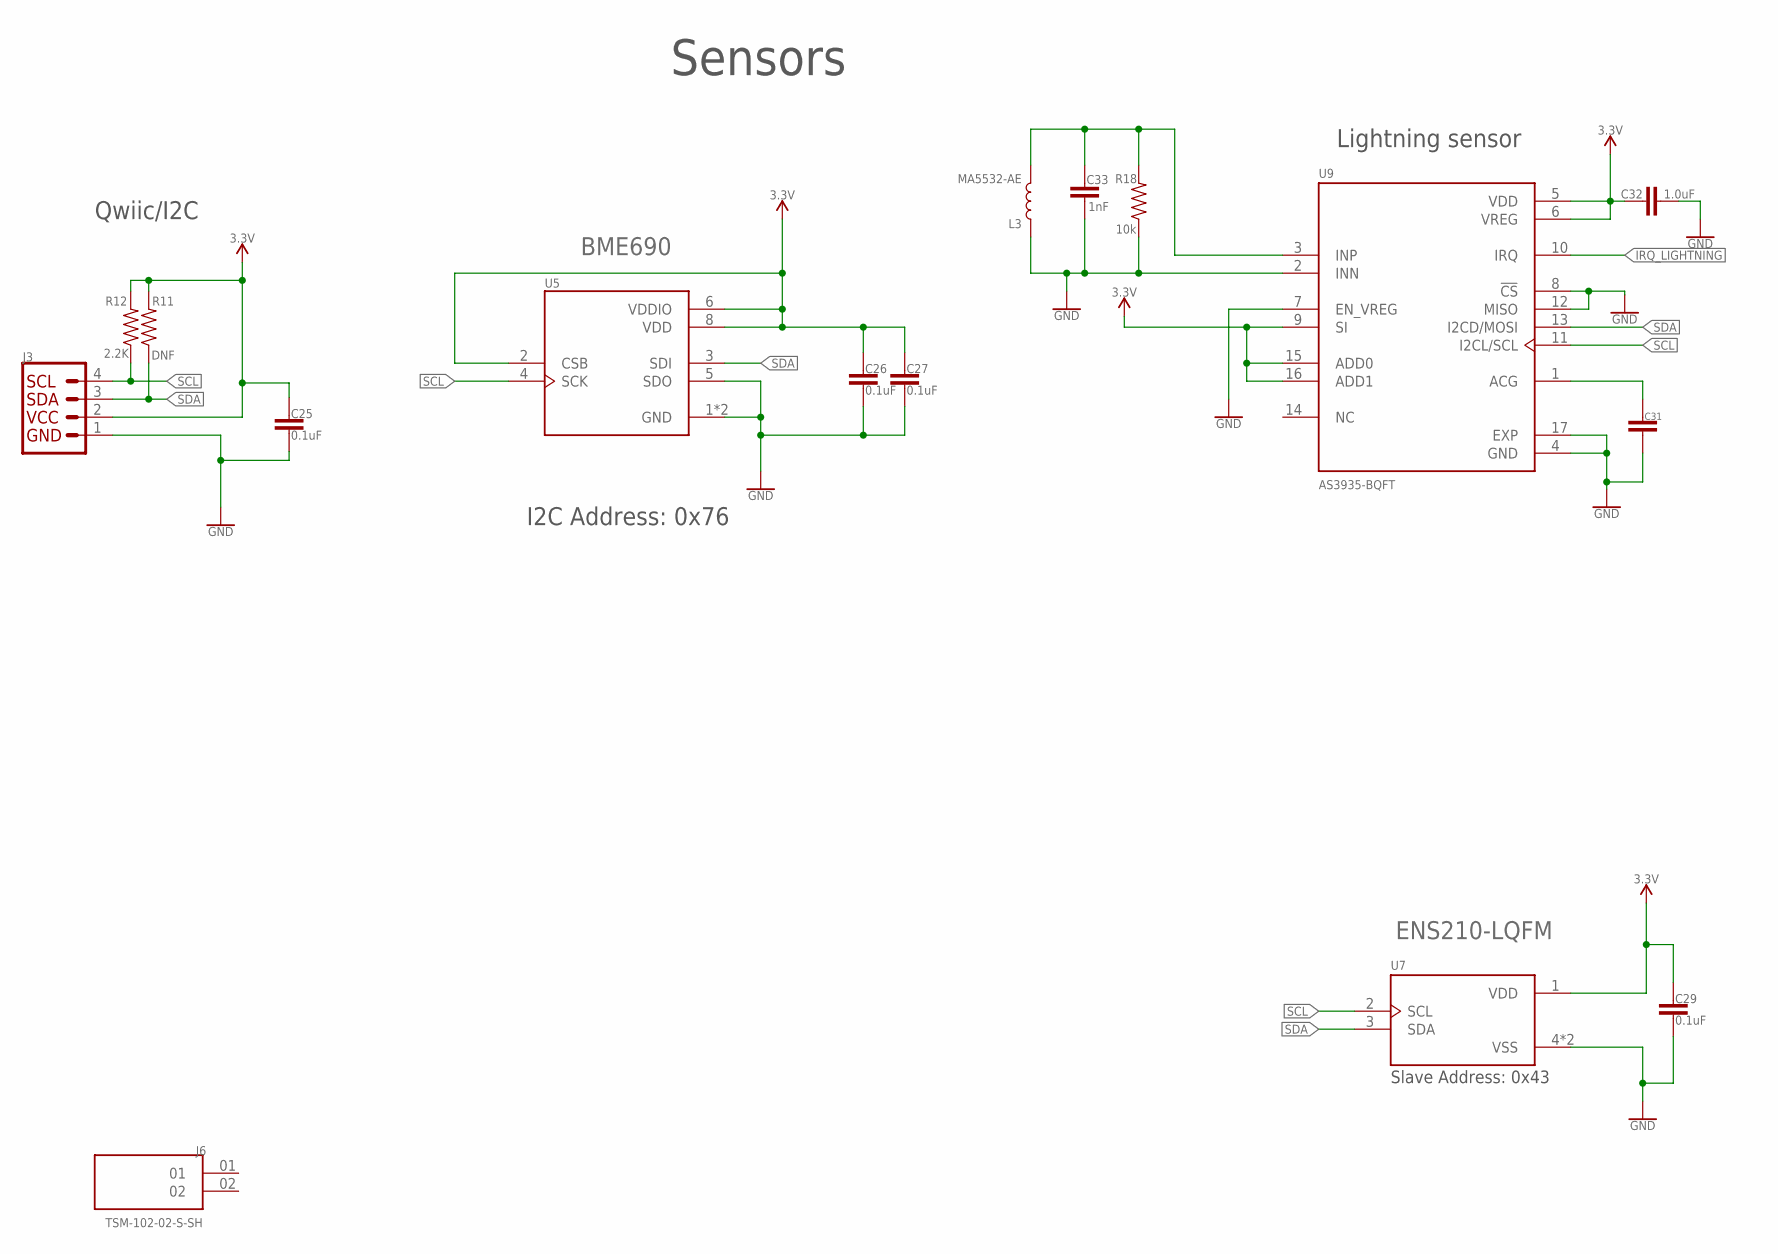
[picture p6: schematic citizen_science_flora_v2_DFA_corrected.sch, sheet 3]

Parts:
C25, C26, C27, C29: 0.1uF; 0402
C31: 10UF0402; 0402
C32: 1.0uF; 0402
C33: 1nF; 0402
J3: QWIIC_CONNECTORJS-1MM; 1X04_1MM_RA
J6: TSM-102-02-S-SH; SAMTEC_TSM-102-02-S-SH
L3: MA5532-AE
R11: DNF; 0402
R12: 2.2K; 0402
R18: 10k; 0402
U5: BME690; IC_BME688
U7: ENS210-LQFM; XDCR_ENS210-LQFM
U9: AS3935-BQFT; QFN65P400X400X80-17N

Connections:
3.3V: C25.1, C26.1, C27.1, C29.1, C32.1, J3.2, R11.2, R12.2, U5.2 (CSB), U5.6 (VDDIO), U5.8 (VDD), U7.1 (VDD), U9.5 (VDD), U9.6 (VREG), U9.9 (SI), U9.15 (ADD0), U9.16 (ADD1); also elsewhere on the board
GND: C25.2, C26.2, C27.2, C29.2, C31.2, C32.2, C33.2, J3.1, L3.1, R18.1, U5.1 (GND), U5.5 (SDO), U5.7 (GND), U7.4 (VSS), U7.5 (VSS), U9.2 (INN), U9.4 (GND), U9.7 (EN_VREG), U9.8 (!CS), U9.12 (MISO), U9.17 (EXP); also elsewhere on the board
IRQ_LIGHTNING: U9.10 (IRQ); also elsewhere on the board
unnamed: C31.1, U9.1 (ACG)
unnamed: C33.1, L3.2, R18.2, U9.3 (INP)
SCL: J3.4, R12.1, U5.4 (SCK), U7.2 (SCL), U9.11 (I2CL/SCL); also elsewhere on the board
SDA: J3.3, R11.1, U5.3 (SDI), U7.3 (SDA), U9.13 (I2CD/MOSI); also elsewhere on the board

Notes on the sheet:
Sensors
Qwiic/I2C
Slave Address: 0x43
Lightning sensor
I2C Address: 0x76

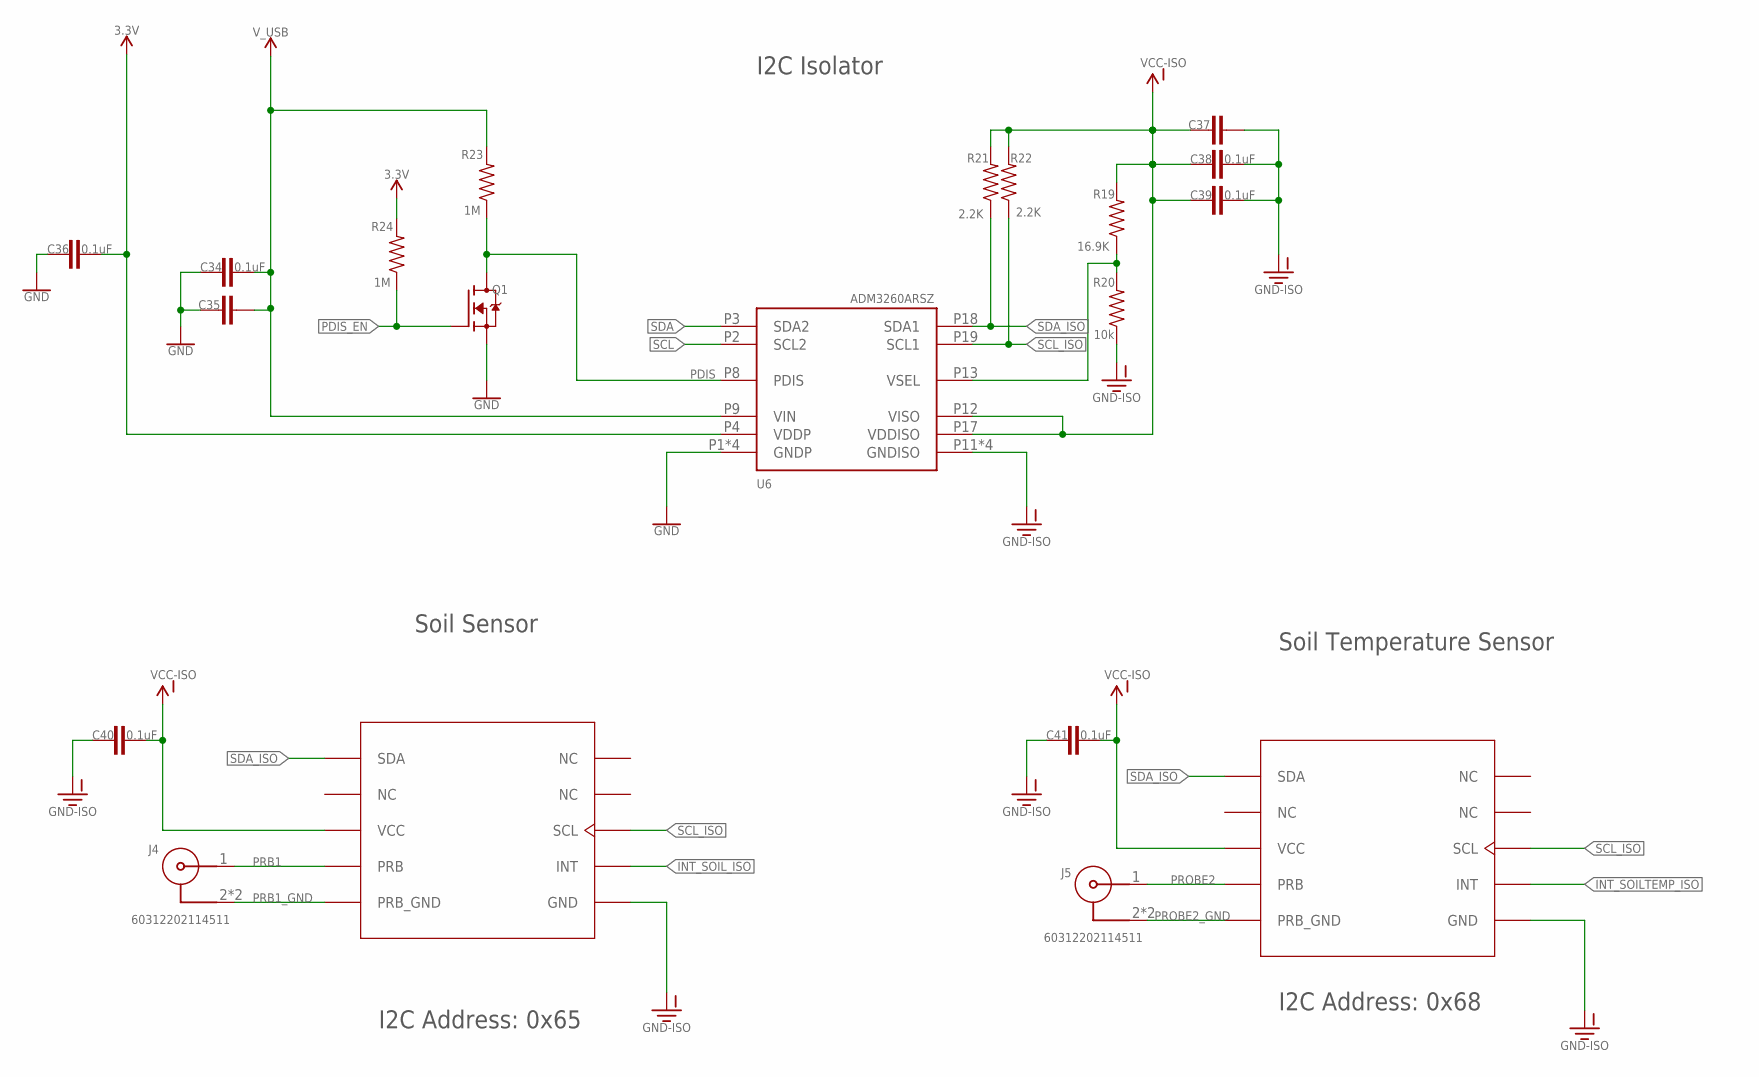
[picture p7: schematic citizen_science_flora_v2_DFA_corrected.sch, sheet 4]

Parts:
C34, C36, C38, C39, C40, C41: 0.1uF; 0402
C35, C37: 10UF0402; 0402
J4, J5: 60312202114511
Q1: BSS138; SOT95P240X111-3N
R19: 16.9K; 0402
R20: 10k; 0402
R21, R22: 2.2K; 0402
R23, R24: 1M; 0402
U6: ADM3260ARSZ; SSOP20
U$2, U$3: PH-OEM; PH_SENSOR

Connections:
3.3V: C36.2, R24.2, U6.P4 (VDDP); also elsewhere on the board
GND: C34.1, C35.1, C36.1, Q1.2 (S), U6.P1 (GNDP), U6.P5 (GNDP), U6.P7 (GNDP), U6.P10 (GNDP); also elsewhere on the board
GND-ISO: C37.2, C38.2, C39.2, C40.1, C41.1, R20.1, U6.P11 (GNDISO), U6.P14 (GNDISO), U6.P16 (GNDISO), U6.P20 (GNDISO), U$2.P$6 (GND), U$3.P$6 (GND); also elsewhere on the board
INT_SOILTEMP_ISO: U$3.P$7 (INT); also elsewhere on the board
INT_SOIL_ISO: U$2.P$7 (INT); also elsewhere on the board
unnamed: R19.1, R20.2, U6.P13 (VSEL)
PDIS: Q1.3 (D), R23.1, U6.P8 (PDIS)
PDIS_EN: Q1.1 (G), R24.1; also elsewhere on the board
PRB1: J4.1, U$2.P$4 (PRB)
PRB1_GND: J4.2, J4.3 (2), U$2.P$5 (PRB_GND)
PROBE2: J5.1, U$3.P$4 (PRB)
PROBE2_GND: J5.2, J5.3 (2), U$3.P$5 (PRB_GND)
SCL: U6.P2 (SCL2); also elsewhere on the board
SCL_ISO: R22.1, U6.P19 (SCL1), U$2.P$8 (SCL), U$3.P$8 (SCL)
SDA: U6.P3 (SDA2); also elsewhere on the board
SDA_ISO: R21.1, U6.P18 (SDA1), U$2.P$1 (SDA), U$3.P$1 (SDA)
VCC-ISO: C37.1, C38.1, C39.1, C40.2, C41.2, R19.2, R21.2, R22.2, U6.P12 (VISO), U6.P17 (VDDISO), U$2.P$3 (VCC), U$3.P$3 (VCC)
V_USB: C34.2, C35.2, R23.2, U6.P9 (VIN); also elsewhere on the board

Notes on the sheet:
I2C Isolator
Soil Sensor
Soil Temperature Sensor
I2C Address: 0x68
I2C Address: 0x65

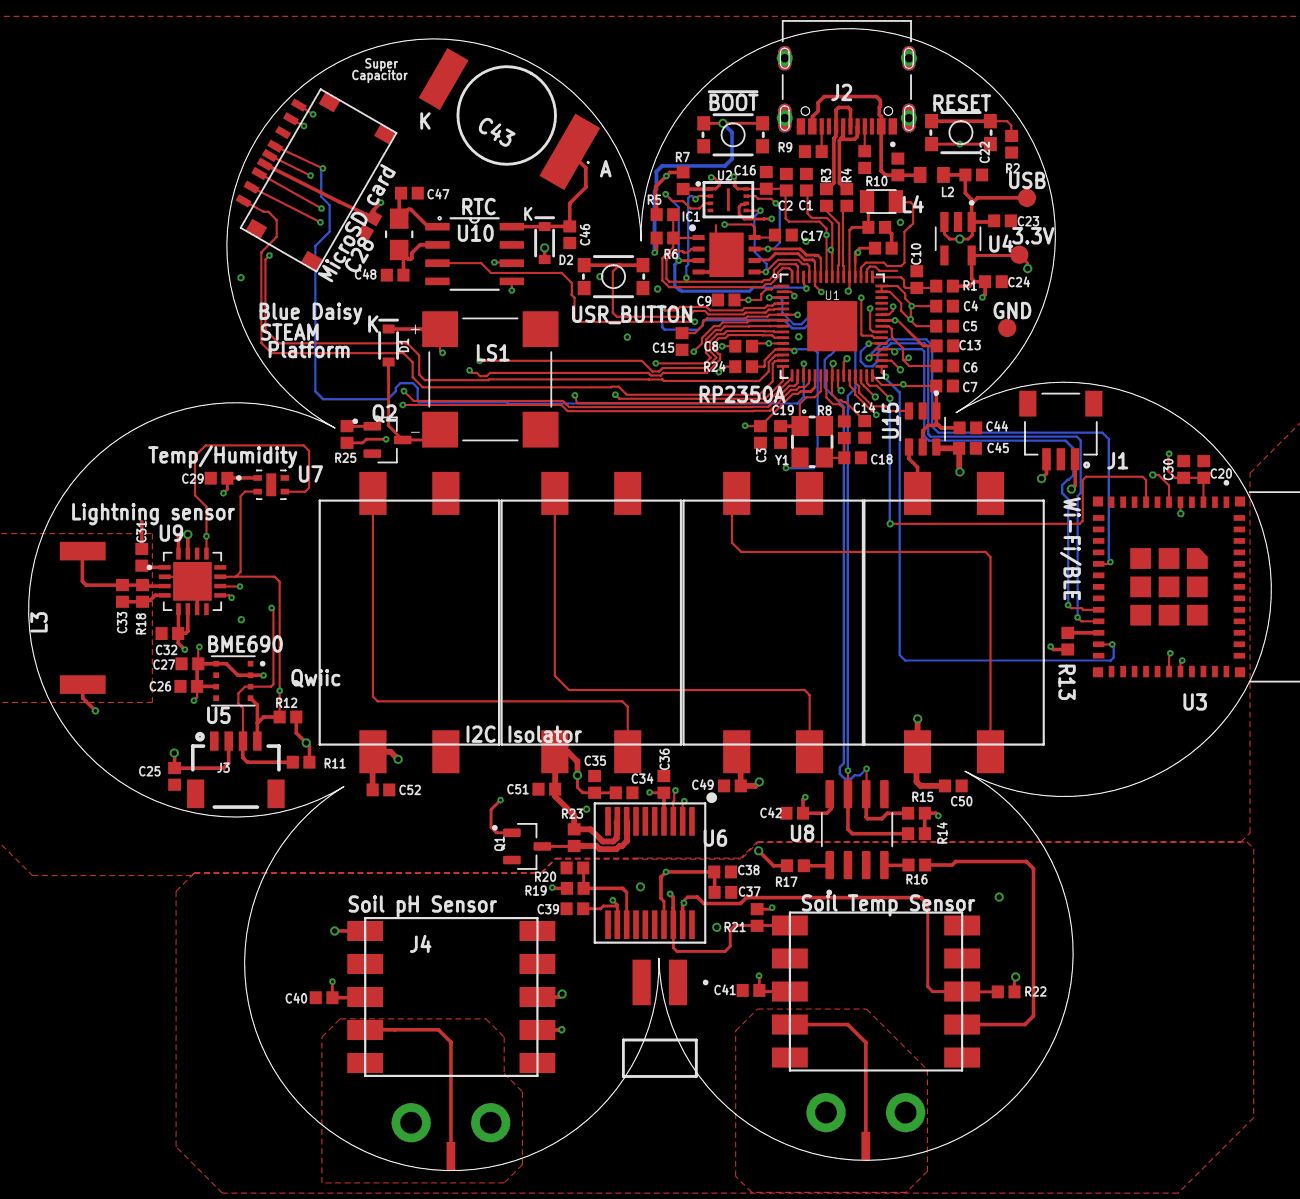
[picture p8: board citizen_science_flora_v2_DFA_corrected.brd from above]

Board: 4 copper layers, 86.6 x 79.6 mm, 118 parts (0 on the bottom side), 80 nets.

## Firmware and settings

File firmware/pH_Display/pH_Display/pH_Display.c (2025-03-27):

#include <stdio.h>
#include "pico/stdlib.h"
#include "hardware/i2c.h"
#include "hardware/pio.h"
#include "hardware/gpio.h"
#include "pico/binary_info.h"
#include "ws2812.pio.h"

// I2C defines
// This example will use I2C0 on GPIO8 (SDA) and GPIO9 (SCL) running at 400KHz.
// Pins can be changed, see the GPIO function select table in the datasheet for information on GPIO assignments
#define I2C_PORT i2c0
#define I2C_SDA 24
#define I2C_SCL 25

#define PDIS_EN 8
#define SOIL_INT 1
#define SOILTEMP_INT 2
#define WS2812_PIN 16

#define PH_REGISTER 4
#define PH_BYTES 4
#define PH_ADDRESS 0x65
#define RTD_ADDRESS 0x68

#define PH_BYTES 4
#define PH_ADDRESS 0x65
#define RTD_ADDRESS 0x68

#define I2C_TIMEOUT 4

#define VERSION_REG     0x00
#define INTERRUPT_REG   0x04
#define ACTIVE_REG      0x06
#define READING_REG     0x16

#define INT_INVERT      0x08
#define ACTIVATE        0x01

#define IS_RGBW false
#define NUM_PIXELS 32

bool new_pH_reading = false;
uint8_t i2c_buf_write[2];
uint8_t i2c_buf_read[4];

const uint8_t seven_seg_lookup[] = {
    0x3F,//0 
    0x06,//1 
    0x5B,//2 
    0x4F,//3 
    0x66,//4 
    0x6D,//5 
    0x7D,//6
    0x07,//7 
    0x7F,//8
    0x6F//9
};

union pH_buffer                
{
	uint8_t i2c_data[4];      //i2c data is written into this buffer          
	uint32_t intermittent_data;	 // this variable is cast to float to read pH
};

void pH_callback(uint gpio, uint32_t events){
    new_pH_reading = true;
}

void i2c_read(uint8_t dev_addr, uint8_t reg, uint8_t len){
    i2c_buf_write[0] = reg;
    i2c_write_blocking_until(I2C_PORT, dev_addr, i2c_buf_write, 1, true, make_timeout_time_ms(I2C_TIMEOUT));
    
    i2c_read_blocking_until(I2C_PORT, dev_addr, i2c_buf_read, len, true, make_timeout_time_ms(I2C_TIMEOUT));
}

void i2c_write(uint8_t dev_addr, uint8_t reg, uint8_t command, uint8_t length){
    i2c_buf_write[0] = reg;
    i2c_buf_write[1] = command;
    i2c_write_blocking_until(I2C_PORT, PH_ADDRESS, i2c_buf_write, length, true, make_timeout_time_ms(100));
}

static inline void put_pixel(PIO pio, uint sm, uint32_t pixel_grb) {
    pio_sm_put_blocking(pio, sm, pixel_grb << 8u);
}

static inline uint32_t urgb_u32(uint8_t r, uint8_t g, uint8_t b) {
    return
            ((uint32_t) (r) << 8) |
            ((uint32_t) (g) << 16) |
            (uint32_t) (b);
}

int main()
{
    union pH_buffer pH_data;
    float pH_value;
    uint16_t pH_number;
    bool reading_enabled = false;

    PIO pio;
    uint sm;
    uint offset;
    int counter = 0;
    uint8_t pos_nums[4] = {0, 0, 0, 0};

    stdio_init_all();
    /* Wait for serial port to connect*/

    printf("\n pH Meter Display\n");

    // I2C Initialisation. Using it at 400Khz.
    i2c_init(I2C_PORT, 100*1000);
    
    gpio_set_function(I2C_SDA, GPIO_FUNC_I2C);
    gpio_set_function(I2C_SCL, GPIO_FUNC_I2C);

    gpio_init(PDIS_EN);
    gpio_init(SOIL_INT);
    gpio_init(SOILTEMP_INT);

    gpio_set_dir(PDIS_EN, true);
    gpio_set_dir(SOIL_INT, false);
    gpio_set_dir(SOILTEMP_INT, false);
    
    // Enable I2C Isolator
    gpio_put(PDIS_EN, true);
    gpio_set_irq_enabled_with_callback(SOIL_INT, GPIO_IRQ_EDGE_FALL | GPIO_IRQ_EDGE_RISE, true, &pH_callback);
    
    // Make the I2C pins available to picotool
    bi_decl(bi_2pins_with_func(I2C_SDA, I2C_SCL, GPIO_FUNC_I2C));
    
    bool success = pio_claim_free_sm_and_add_program_for_gpio_range(&ws2812_program, &pio, &sm, &offset, WS2812_PIN, 1, true);
    hard_assert(success);

    ws2812_program_init(pio, sm, offset, WS2812_PIN, 800000, IS_RGBW);
    for(uint8_t i = 0; i < NUM_PIXELS; i++){
        put_pixel(pio, sm, urgb_u32(0, 0, 0));
    }
    
    while (true) {
        while(!reading_enabled){
            
            i2c_read(PH_ADDRESS, VERSION_REG, 2);

            if(i2c_buf_read[0] == 1 && !reading_enabled){
                reading_enabled = true;
                printf("Setup complete\n");
            } else{
                continue;
            }

            i2c_write(PH_ADDRESS, INTERRUPT_REG, INT_INVERT, 2);
            i2c_write(PH_ADDRESS, ACTIVE_REG, ACTIVATE, 2);
            
            i2c_read(PH_ADDRESS, READING_REG, 4);

            pH_data.i2c_data[3] = i2c_buf_read[0];
            pH_data.i2c_data[2] = i2c_buf_read[1];
            pH_data.i2c_data[1] = i2c_buf_read[2];
            pH_data.i2c_data[0] = i2c_buf_read[3];

            pH_value = (float)pH_data.intermittent_data;
            pH_value /= 1000.0;
            printf("pH value = %2.2f\n", pH_value);
        }

        if(new_pH_reading){
            i2c_read(PH_ADDRESS, READING_REG, 4);

            pH_data.i2c_data[3] = i2c_buf_read[0];
            pH_data.i2c_data[2] = i2c_buf_read[1];
            pH_data.i2c_data[1] = i2c_buf_read[2];
            pH_data.i2c_data[0] = i2c_buf_read[3];

            pH_value = (float)pH_data.intermittent_data;
            pH_value /= 1000.0;
            printf("pH value = %3.2f\n", pH_value);
            pH_number = (uint16_t)(pH_value * 100);

            for(uint8_t i = 0; i < 4; i++){
                pos_nums[i] = pH_number % 10;
                pH_number = pH_number / 10;
            }

            for(uint8_t i = 0; i < 4; i++){
                uint8_t digit = seven_seg_lookup[pos_nums[i]];
                if(i == 2){
                    digit |= 0x80;
                }
                for(uint8_t j = 0; j < 8; j++){
                    if((1 << j) & digit){
                        put_pixel(pio, sm, urgb_u32(0, 0, 0xFF));
                    } else{
                        put_pixel(pio, sm, urgb_u32(0, 0, 0));
                    }
                }
            }
            new_pH_reading = false;
        }
    }
}

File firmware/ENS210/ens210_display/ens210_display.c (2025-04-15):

#include <stdio.h>
#include "pico/stdlib.h"
#include "hardware/i2c.h"
#include "ScioSense_Ens21x.h"
#include "string.h"

// I2C defines
// This example will use I2C0 on GPIO8 (SDA) and GPIO9 (SCL) running at 400KHz.
// Pins can be changed, see the GPIO function select table in the datasheet for information on GPIO assignments
#define I2C_PORT i2c0
#define I2C_SDA 24
#define I2C_SCL 25
#define I2C_TIMEOUT make_timeout_time_ms(10)
#define ENS210_ADDR 0x43

void delay(uint32_t duration){
    sleep_ms(duration);
}

//Result  (*read)     (void* config, const uint16_t address, uint8_t* data, const size_t size);
Result i2c_read(void* config, const uint16_t address, uint8_t* data, const size_t size)
{
    uint8_t ret;
    uint8_t write_buf = address;

    ret = i2c_write_blocking_until(config, ENS210_ADDR, &write_buf, 1, true, I2C_TIMEOUT);
    if(ret != 1)
    {
        return RESULT_IO_ERROR;
    }

    ret = i2c_read_blocking_until(config, ENS210_ADDR, data, size, false, I2C_TIMEOUT);
    if(ret != size)
    {
        return RESULT_IO_ERROR;
    }
    return RESULT_OK;
}
//Result  (*write)    (void* config, const uint16_t address, uint8_t* data, const size_t size);
Result i2c_write(void* config, uint16_t address, uint8_t* data, const size_t size)
{
    uint8_t ret;
    uint8_t write_buffer[size + 1];

    write_buffer[0] = address;
    memcpy(&write_buffer[1], data, size);

    ret = i2c_write_blocking_until(config, ENS210_ADDR, write_buffer, size + 1, true, I2C_TIMEOUT);
    if(ret != (size + 1))
    {
        printf("Failed to write to i2c bus.\n");
        return RESULT_IO_ERROR;
    }

    return RESULT_OK;
}

int main()
{
    ScioSense_Ens21x_IO temp_sensor;
    temp_sensor.wait = &delay;

    stdio_init_all();

    // I2C Initialisation. Using it at 400Khz.
    i2c_init(I2C_PORT, 400*1000);
    
    gpio_set_function(I2C_SDA, GPIO_FUNC_I2C);
    gpio_set_function(I2C_SCL, GPIO_FUNC_I2C);
    // For more examples of I2C use see https://github.com/raspberrypi/pico-examples/tree/master/i2c

    while (true) {
        printf("Hello, world!\n");
        sleep_ms(1000);
    }
}
;

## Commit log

2024-12-28 Daily check-in
    [citizen_science_flora.sch]
2025-01-01 Added floral outline
    [citizen_science_flora.brd, citizen_science_flora.sch]
2025-01-02 placed some components
    [citizen_science_flora.brd, citizen_science_flora.sch]
2025-01-03 Add 3D packages to resistors
    [citizen_science_flora.brd, citizen_science_flora.sch]
2025-01-05 Board file updates
    [citizen_science_flora.brd, citizen_science_flora.sch]
2025-01-06 Updates to the design
    [citizen_science_flora.brd, citizen_science_flora.sch]
2025-01-08 updates to brd files
    [citizen_science_flora.brd]
2025-01-15 BoM file check-in
    [citizen_science_flora.brd, citizen_science_flora.sch, citizen_science_flora_top_bom.csv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]
2025-02-08 Change to gerbers
    [citizen_science_flora.brd, citizen_science_flora_bom_v2.xlsx, citizen_science_flora_top_bom.xlsx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]
2025-02-08 Updates to Gerber
    [citizen_science_flora.brd, citizen_science_flora_bom_v2.xlsx, citizen_science_flora_top_bom.xlsx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]
2025-02-10 updated gerber files
    [citizen_science_flora.brd, citizen_science_flora.sch, citizen_science_flora_bom_v2.xlsx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]
2025-02-12 File re-org + DFA corrected version
    [BoM_Citizen_Science_Paper.xlsx, Next PCB DFA Report T-E26182AA1.xlsx, citizen_science_flora.brd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]
2025-02-14 RP2040 design
    [citizen_science_flora_RP2040.brd, citizen_science_flora_RP2040.sch, citizen_science_flora_top_bom.csv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]
2025-02-15 update to design files
    [citizen_science_flora_RP2040.brd, citizen_science_flora_RP2040.sch]
2025-02-15 Board design files and BoM
    [citizen_science_flora_RP2040.brd, citizen_science_flora_RP2040.sch, citizen_science_flora_RP2040_bom.xlsx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]
2025-02-18 Updates to board design
    [citizen_science_flora_RP2040.brd, citizen_science_flora_RP2040.sch]
2025-02-19 via and new gerber
    Added a new via and generated new gerbers
    [citizen_science_flora_v2_DFA_corrected.brd]
2025-03-27 pH Display firmware
    [citizen_science_flora_top_bom.xlsx]
2025-04-15 Checking in ENS210 drivers

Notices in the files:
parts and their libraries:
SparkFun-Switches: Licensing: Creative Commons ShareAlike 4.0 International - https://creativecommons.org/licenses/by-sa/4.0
